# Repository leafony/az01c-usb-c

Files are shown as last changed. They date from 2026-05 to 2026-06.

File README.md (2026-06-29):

# Leafony AZ01C USB-C シリアル変換リーフ

## 概要

Leafony AZ01C は、Leafony Bus 向けの USB-C to UART リーフである。USB 接続時は FT234XD による USB-UART 変換と、USB VBUS から生成した 3.3V 電源を Leafony Bus へ供給する。

USB 未接続時に他リーフ側のバッテリーから 3.3V が供給される構成でも、UART 信号線と 3.3V 電源ラインのバックフィードを抑え、USB-C リーフ側が無駄な電力を消費しないことを設計方針とする。信号線は TS3A4741 で物理的に切断し、電源ラインは TPS6282533 出力と Leafony Bus 3.3V の間に MAX40200AUK+T 理想ダイオードを入れて逆流を遮断する。

## 主な用途

- Leafony リーフへの MCU 書き込み
- Leafony リーフの UART デバッグ
- USB から Leafony Bus への 3.3V 電源供給

## 仕様

### 電気的仕様

| 項目 | Min | Typ | Max | 単位 | 備考 |
|---|---:|---:|---:|---|---|
| USB VBUS 入力電圧 | 4.5 | 5.0 | 5.5 | V | USB-C UFP/Sink として使用 |
| Buck 出力電圧 `P3V3_BUCK` | 3.27 | 3.30 | 3.33 | V | TPS6282533 固定 3.3V、精度 ±1% |
| Leafony Bus 3.3V 出力 | - | 3.26 | - | V | MAX40200 通過後。500mA 時は約 43mV 低下 |
| Leafony Bus 3.3V 出力電流 | - | - | 500 | mA | TPS6282533 は 2A 品、MAX40200 は 1A 品。本設計では 500mA 上限 |
| MAX40200 逆方向リーク | - | 0.07 | 1.5 | µA | Leafony Bus +3.3V から `P3V3_BUCK` 方向 |
| UART 通信速度 | 300 | - | 3,000,000 | baud | FT234XD 仕様 |
| UART I/O 論理電圧 | - | 3.3 | - | V | FT234XD VCCIO を Leafony Bus 3.3V rail に接続 |
| USB 接続時アイドル消費 | - | 12 | - | mA | FT234XD、Buck、MAX40200、LED 周辺を含む概算 |
| USB 未接続時バッテリー側消費 | - | 0.15 | 2.3 | µA | MAX40200 逆方向リークと TS3A4741 待機電流のデータシート値から算出。FT234XD の VCC=0V、VCCIO=3.3V 条件は実機確認対象 |
| 動作温度範囲 | -40 | 25 | +85 | ℃ | 構成部品の最小共通範囲 |

### 機械的仕様

| 項目 | 仕様 |
|---|---|
| 外形寸法 | Leafony 20mm x 20mm |
| 基板厚 | 0.8mm 推奨 |
| 層数 | 4層 |
| 実装 | 両面実装 |
| USB コネクタ | Hirose CX90M-16P |
| 外部接続 | Leafony Bus 29ピン |

### USB 仕様

| 項目 | 仕様 |
|---|---|
| USB 規格 | USB 2.0 Full Speed (12Mbps) |
| コネクタ | USB Type-C |
| Type-C ロール | UFP / Sink Only |
| CC 抵抗 | CC1, CC2 それぞれ 5.1kΩ で GND へプルダウン |
| USB PD | 非対応 |
| ドライバ | FTDI VCP / D2XX |

## 回路設計

### 電源アーキテクチャ

```
USB VBUS 5V
  |
  +-- FB1 ---------------------> FT234XD.VCC
  |                                |
  |                                +--> FT234XD.3V3OUT
  |                                      |
  |                                      +--> TS3A4741.IN1/IN2
  |
  +----------------------------> TPS6282533.VIN
                                   |
                                   +-- EN = VIN
                                   |
                                   +-- SW -- L1 --> P3V3_BUCK
                                                   |
                                                   +--> MAX40200AUK+T
                                                        VDD = P3V3_BUCK
                                                        EN  = VDD
                                                        OUT = +3.3V rail
                                                              |
                                                              +--> FT234XD.VCCIO
                                                              +--> TS3A4741.V+
                                                              +--> LED1 pull-up
                                                              +--> Leafony Bus 3.3V (CN1 F1/B1)
```

`P3V3_BUCK` は TPS6282533 と MAX40200 の間のローカル電源レール、`+3.3V rail` は MAX40200 後段の Leafony Bus 側電源レールとする。

MAX40200 を入れることで、USB 未接続時に他リーフから Leafony Bus 3.3V が供給されても、`+3.3V rail -> P3V3_BUCK -> TPS6282533.SW/VIN -> VBUS` 方向の逆流を遮断する。MAX40200 の電圧降下により、Leafony Bus 側の実効電圧は TPS6282533 出力より低くなる。

### 動作状態

| 状態 | 電源 | UART 信号線 | 備考 |
|---|---|---|---|
| USB 接続、外部 3.3V なし | TPS6282533 から Leafony Bus へ 3.3V 供給 | TS3A4741 ON | 通常の USB-UART 動作 |
| USB 未接続、外部 3.3V なし | VBUS=0V、`P3V3_BUCK`=0V、Leafony Bus 3.3V=0V | TS3A4741 OFF | 基板側は実質停止 |
| USB 未接続、他リーフから 3.3V 供給 | Leafony Bus 3.3V は外部から印加。MAX40200 が Buck/VBUS 方向の逆流を遮断 | TS3A4741 OFF | FT234XD.3V3OUT=0V のためスイッチ制御は OFF |
| USB 接続、他リーフも 3.3V 供給 | 電源競合に注意 | TS3A4741 ON | 複数電源の同時接続を許容する場合はシステム側で電源 ORing 方針を確認 |

USB 未接続で他リーフから 3.3V が供給される場合、MAX40200 後段の `+3.3V rail` 配下である FT234XD.VCCIO、TS3A4741.V+、LED1 pull-up には電圧がかかる。一方で FT234XD.VCC は VBUS 由来のため 0V であり、FT234XD.3V3OUT も 0V となる。UART の TX/RX は TS3A4741 により切断される。

この状態でバッテリー側から USB-C リーフへ流れる消費電流は、データシート規定値からの見積もりで Typ 約 0.15µA、Max 約 2.3µA とする。内訳は MAX40200 の逆方向リーク Typ 0.07µA / Max 1.5µA と、TS3A4741 の VCC 待機電流 Typ 0.075µA / Max 0.75µA である。FT234XD は VCC=0V、VCCIO=3.3V の条件がデータシート上の通常動作条件ではないため、この見積もりには含めず、実機で USB 未接続時の Leafony Bus 3.3V 電流を確認する。

### バックフィード対策

バックフィード経路は大きく 2 つに分ける。

| 経路 | リスク | 対策 |
|---|---|---|
| UART TX/RX 信号線 | 他リーフ MCU の TX/RX が FT234XD の I/O 保護素子を通じて FT234XD 側を半端に給電する | TS3A4741 を TX/RX に直列挿入し、USB 未接続時は OFF |
| 3.3V 電源ライン | 他リーフの 3.3V が TPS6282533 の SW/L1 側から VIN/VBUS へ逆流する | MAX40200AUK+T を `P3V3_BUCK` と Leafony Bus 3.3V の間に直列挿入 |

TS3A4741 の IN1/IN2 は FT234XD.3V3OUT に接続する。USB 接続時は FT234XD が動作して 3V3OUT が High になり、TX/RX が接続される。USB 未接続時は 3V3OUT が 0V になり、TX/RX が物理的に切断される。

MAX40200 は VDD を `P3V3_BUCK`、OUT を Leafony Bus 3.3V、EN を VDD に接続する。USB 接続時は TPS6282533 から Leafony Bus へ給電し、USB 未接続時は Leafony Bus 3.3V から Buck/VBUS 側への逆流を遮断する。

### USB Type-C UFP 構成

| 信号 | 処理 |
|---|---|
| CC1, CC2 | 各々 5.1kΩ で GND へプルダウン |
| VBUS | A4, A9, B4, B9 をまとめて 5V 入力へ接続 |
| GND | A1, A12, B1, B12 を GND プレーンへ接続 |
| D+, D- | A面/B面の同名信号を基板上で接続し、FT234XD へ配線 |
| SBU1, SBU2 | NC |

USB PD には対応しない。CC 抵抗のみで USB Type-C の Sink/UFP として認識させる。

### ESD 保護

D+/D- ラインには USBLC6-2P6 を配置する。USB-C コネクタ近傍に置き、D+/D- へのスタブを短くする。VBUS は FB1 を通して基板内へ引き込む。必要に応じて、VBUS 用 TVS ダイオードの追加余地を検討する。

### 通信インジケータ LED

FT234XD の CBUS0 を FT_PROG で `TX&RXLED#` に設定し、LED1 を TX/RX 共用インジケータとして使用する。

## Leafony Bus ピンアサイン

| ピン名 | F面 / B面 | 信号 | 用途 |
|---|---|---|---|
| 3.3V | F1 / B1 | +3.3V rail | MAX40200 通過後の 3.3V 電源。USB から他リーフへ最大 500mA 供給 |
| VBUS | F3 / B3 | VBUS 5V | USB VBUS。必要な他リーフで参照可能 |
| D0 | F18 / B18 | UART TX | FT234XD TXD から他リーフ MCU RX へ。TS3A4741 Ch1 経由 |
| D1 | F20 / B20 | UART RX | 他リーフ MCU TX から FT234XD RXD へ。TS3A4741 Ch2 経由 |
| GND | F27 / B27 | GND | 共通グラウンド |

## 主要部品

| Ref | 型番 | 役割 |
|---|---|---|
| U1 | TS3A4741DCNR | UART TX/RX 切断用 2ch SPST アナログスイッチ |
| U2 | USBLC6-2P6 | USB D+/D- ESD 保護 |
| U3 | FT234XD | USB-UART ブリッジ |
| U4 | TPS6282533DMQR | 5V から 3.3V を生成する Buck コンバータ |
| U5 | MAX40200AUK+T | 3.3V 電源ライン逆流防止用 ideal diode |
| J1 | CX90M-16P | USB Type-C レセプタクル |
| L1 | 0.47uH | TPS6282533 用インダクタ |
| FB1 | 600Ω @ 100MHz | VBUS 入力ノイズ抑制 |

## ソフトウェア

### ドライバ

FTDI 公式の VCP または D2XX ドライバを使用する。

| OS | ドライバ | 備考 |
|---|---|---|
| Windows 10/11 | 標準ドライバ自動インストール | 必要に応じて FTDI 公式ドライバを使用 |
| macOS | 標準 Apple FTDI ドライバ | macOS 10.9 以降 |
| Linux | `ftdi_sio` | 多くのディストリビューションで自動認識 |

### 初期設定 (FT_PROG)

量産前に FT234XD 内蔵 MTP へ以下を設定する。

| パラメータ | 設定値 | 備考 |
|---|---|---|
| CBUS0 Function | `TX&RXLED#` | LED1 通信インジケータ用 |
| Manufacturer Name | 任意 | 例: `mitdir` |
| Product Description | 任意 | 例: `Leafony USB-UART Bridge` |
| Serial Number | ユニーク値 | 複数台接続時の識別用 |
| USB Vendor ID | `0x0403` | FTDI デフォルト |
| USB Product ID | `0x6015` | FT-X デフォルト |

## 設計反映メモ

この README は、MAX40200AUK+T を追加した電源構成を前提とする。KiCad 回路図、PCB、BOM を更新する場合は、少なくとも以下を反映する。

- `U5: MAX40200AUK+T` を追加する
- TPS6282533 の出力側を `P3V3_BUCK` とし、Leafony Bus 側 `+3.3V rail` と分離する
- MAX40200 の VDD を `P3V3_BUCK`、OUT を `+3.3V rail`、EN を VDD に接続する
- Leafony Bus 3.3V、FT234XD.VCCIO、TS3A4741.V+、LED1 pull-up は MAX40200 後段の `+3.3V rail` に接続する
- BOM に MAX40200AUK+T と対応フットプリントを追加する

あわせて以下を実機またはデータシートで確認する。

- USB 未接続かつ他リーフから 3.3V が供給される状態で、FT234XD.VCC=0V、FT234XD.VCCIO=3.3V となることを許容できるか
- USB 接続中に他リーフ側の 3.3V 電源も同時に有効になるシステム構成を許容するか
- MAX40200 の電圧降下込みで、Leafony Bus 側 3.3V rail の最小電圧が接続先リーフの要求を満たすか

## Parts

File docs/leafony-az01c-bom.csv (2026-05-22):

Reference | Value | Datasheet | Footprint | Qty | DNP | MANUFACTURER | MPN
C1,C2,C4,C5,C10 | 0.1uF(K)/50V/X5R | https://yageogroup.com/content/datasheet/asset/file/UPY-GPHC_X5R_4V-TO-50V | Capacitor_SMD:C_0402_1005Metric | 5 |  | YAGEO | CC0402KRX5R9BB104
C3 | 4.7uF(M)/6.3V/X5R | https://yageogroup.com/content/datasheet/asset/file/UPY-GPHC_X5R_4V-TO-50V | Capacitor_SMD:C_0402_1005Metric | 1 |  | YAGEO | CC0402MRX5R5BB475
C6 | 10nF(K)/50V/X7R | https://yageogroup.com/content/datasheet/asset/file/UPY-GPHC_X7R_6.3V-TO-50V | Capacitor_SMD:C_0402_1005Metric | 1 |  | YAGEO | CC0402KRX7R9BB103
C7 | 4.7uF(K) 10V X5R | https://yageogroup.com/content/datasheet/asset/file/UPY-GPHC_X5R_4V-TO-50V | Capacitor_SMD:C_0603_1608Metric | 1 |  | YAGEO | CC0603KRX5R6BB475
C8,C9 | 10uF(M) 10V X5R | https://yageogroup.com/content/datasheet/asset/file/UPY-GPHC_X5R_4V-TO-50V | Capacitor_SMD:C_0603_1608Metric | 2 |  | YAGEO | CC0603MRX5R6BB106
D1 | Red LED | https://www.rohm.com/products/led/chip-leds-mono-color-type/standard/sml-d14vw_a_-product | LED_SMD:LED_0603_1608Metric | 1 |  | ROHM | SML-D14VWT86AAS
FB1 | 600 Ohms @ 100 MHz | https://www.laird.com/document/datasheet/mi0805k601r-10-datasheet | Inductor_SMD:L_0805_2012Metric | 1 |  | Laird | MI0805K601R-10
J1 | CX90M-16P | https://www.hirose.com/product/document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 | Leafony:HRS_CX90M-16P | 1 |  | Hirose | CX90M-16P
L1 | 0.47uH(M) 3.6A | https://search.murata.co.jp/Ceramy/image/img/P02/J(E)TE243A-0001.pdf | Inductor_SMD:L_Murata_DFE201610P | 1 |  | Murata Electronics | DFE201610E-R47M=P2
R1 | 10k(J) | https://yageogroup.com/content/datasheet/asset/file/PYU-RC_GROUP_51_ROHS_L | Resistor_SMD:R_0402_1005Metric | 1 |  | YAGEO | RC0402JR-0710KL
R2 | 270R(J) | https://yageogroup.com/content/datasheet/asset/file/PYU-RC_GROUP_51_ROHS_L | Resistor_SMD:R_0402_1005Metric | 1 |  | YAGEO | RC0402JR-07270RL
R3,R4 | 5.1k(J) | https://yageogroup.com/content/datasheet/asset/file/PYU-RC_GROUP_51_ROHS_L | Resistor_SMD:R_0402_1005Metric | 2 |  | YAGEO | RC0402JR-075K1L
U1 | TS3A4741DCNR | https://www.ti.com/lit/gpn/ts3a4741 | Package_TO_SOT_SMD:SOT-23-8 | 1 |  | Texas Instruments | TS3A4741DCNR
U2 | USBLC6-2P6 | https://www.st.com/resource/en/datasheet/usblc6-2.pdf | Package_TO_SOT_SMD:SOT-666 | 1 |  | STMicroelectronics | USBLC6-2P6
U3 | FT234XD | https://ftdichip.com/wp-content/uploads/2024/05/DS_FT234XD.pdf | Package_DFN_QFN:WDFN-12-1EP_3x3mm_P0.45mm_EP1.7x2.5mm | 1 |  | FTDI | FT234XD-T
U4 | TPS6282533DMQR | https://www.ti.com/lit/gpn/tps62825 | Leafony:DMQ0006A | 1 |  | Texas Instruments | TPS6282533DMQR
U5 | MAX40200AUK+T | https://datasheets.maximintegrated.com/en/ds/MAX40200.pdf | Package_TO_SOT_SMD:SOT-23-5 | 1 |  | Analog Devices Inc./Maxim Integrated | MAX40200AUK+T

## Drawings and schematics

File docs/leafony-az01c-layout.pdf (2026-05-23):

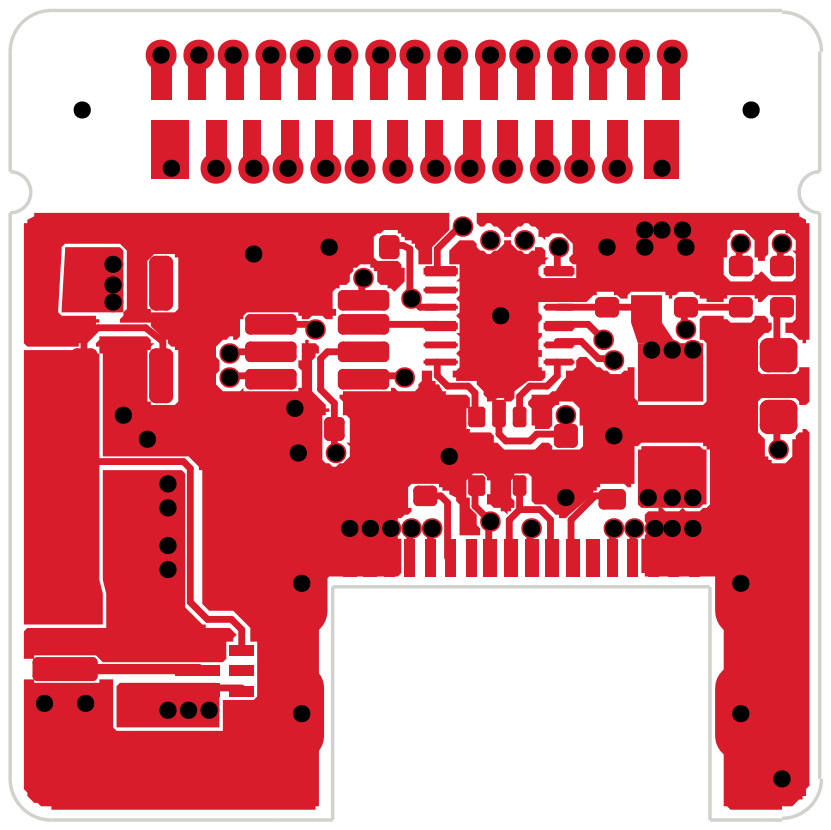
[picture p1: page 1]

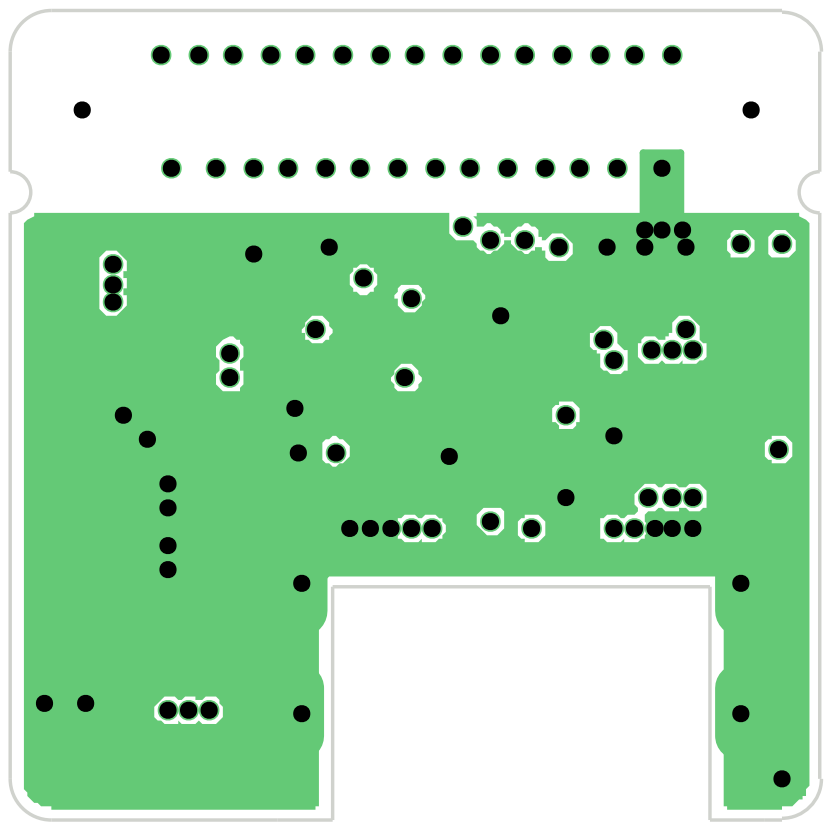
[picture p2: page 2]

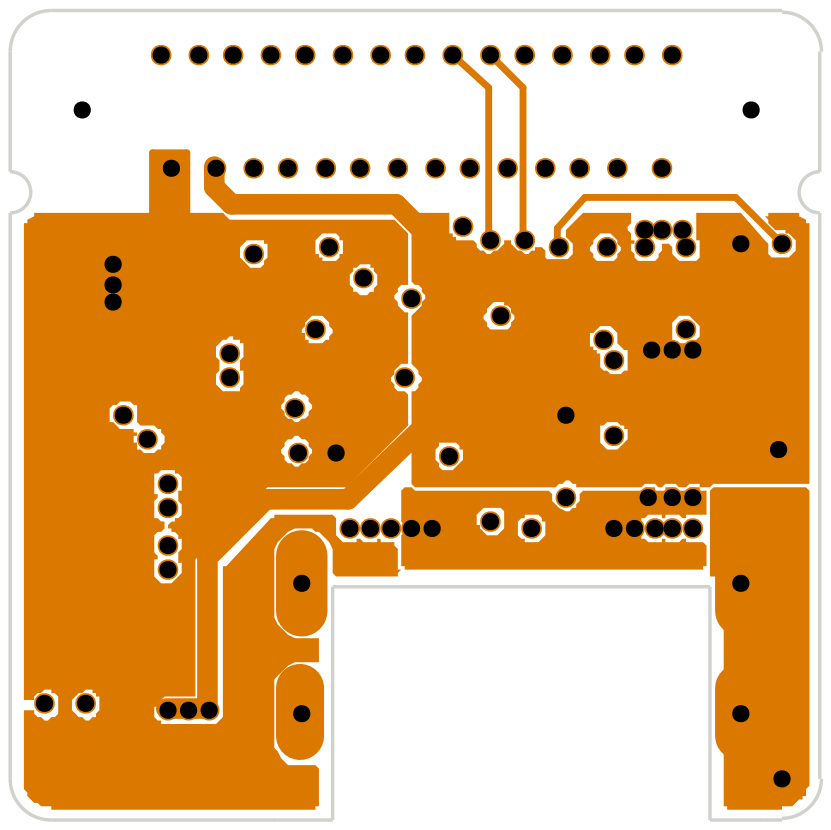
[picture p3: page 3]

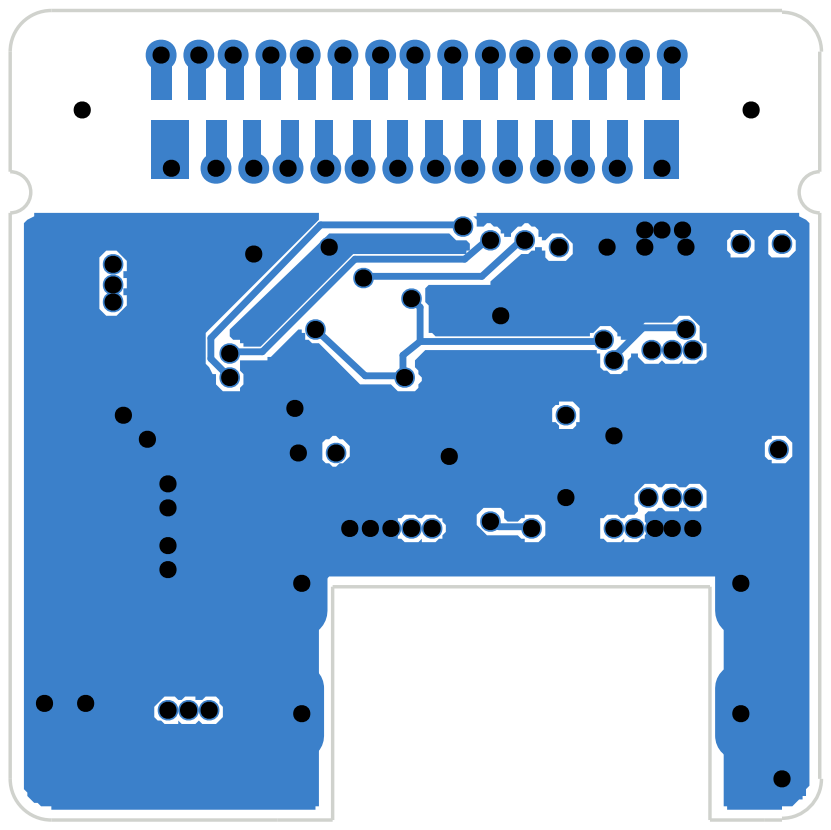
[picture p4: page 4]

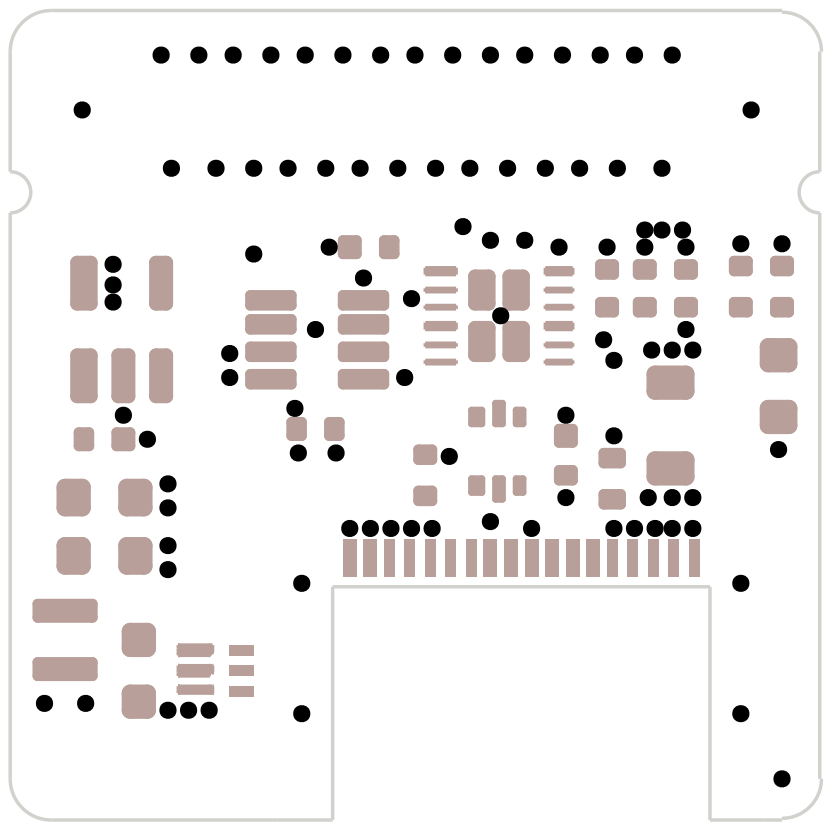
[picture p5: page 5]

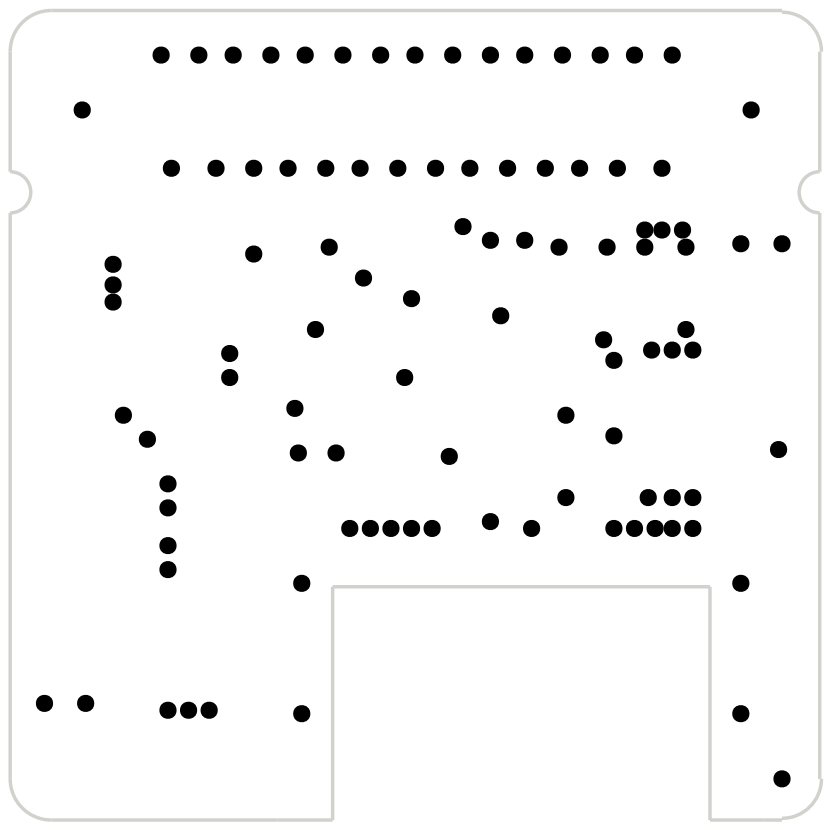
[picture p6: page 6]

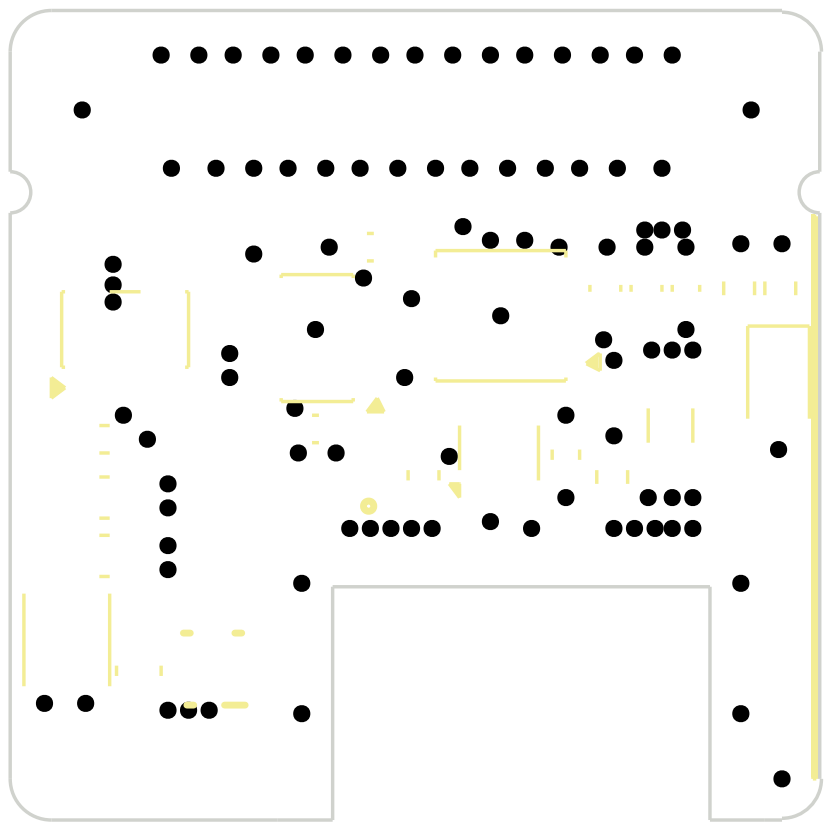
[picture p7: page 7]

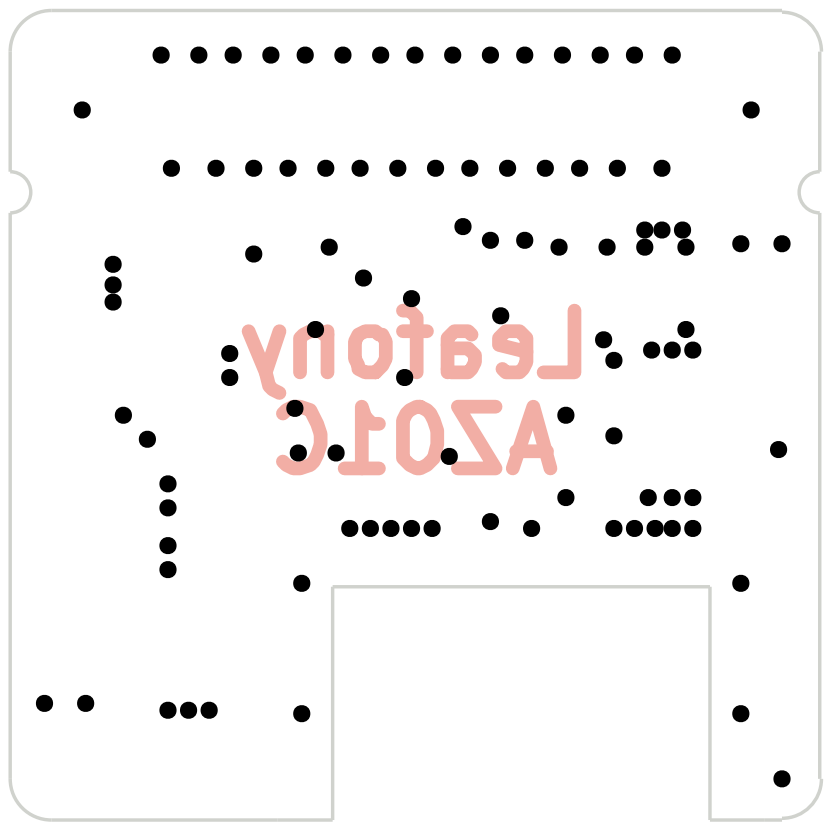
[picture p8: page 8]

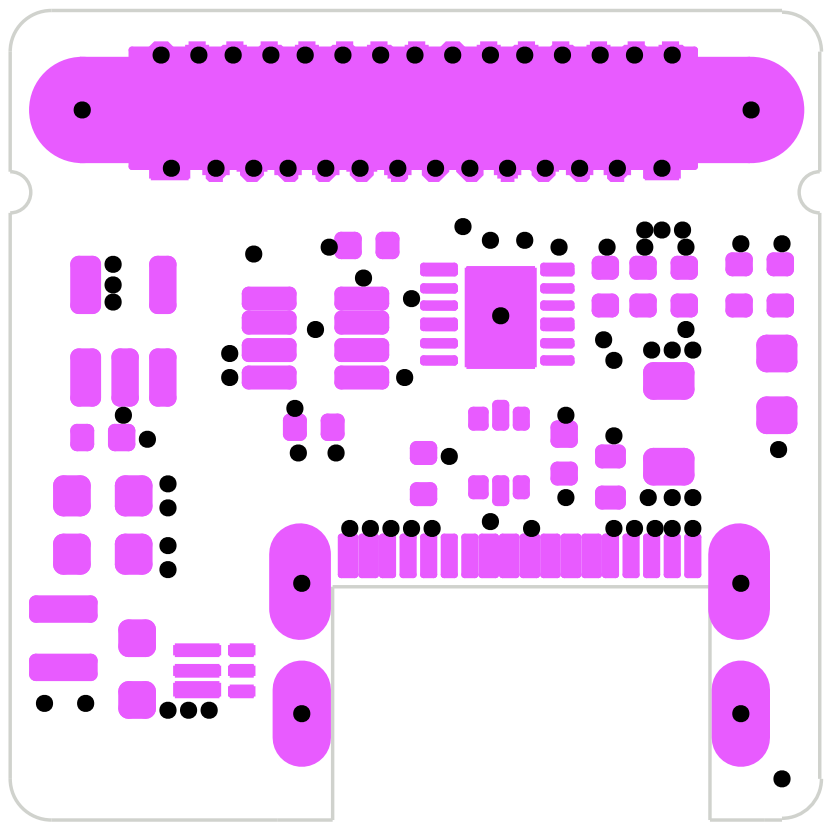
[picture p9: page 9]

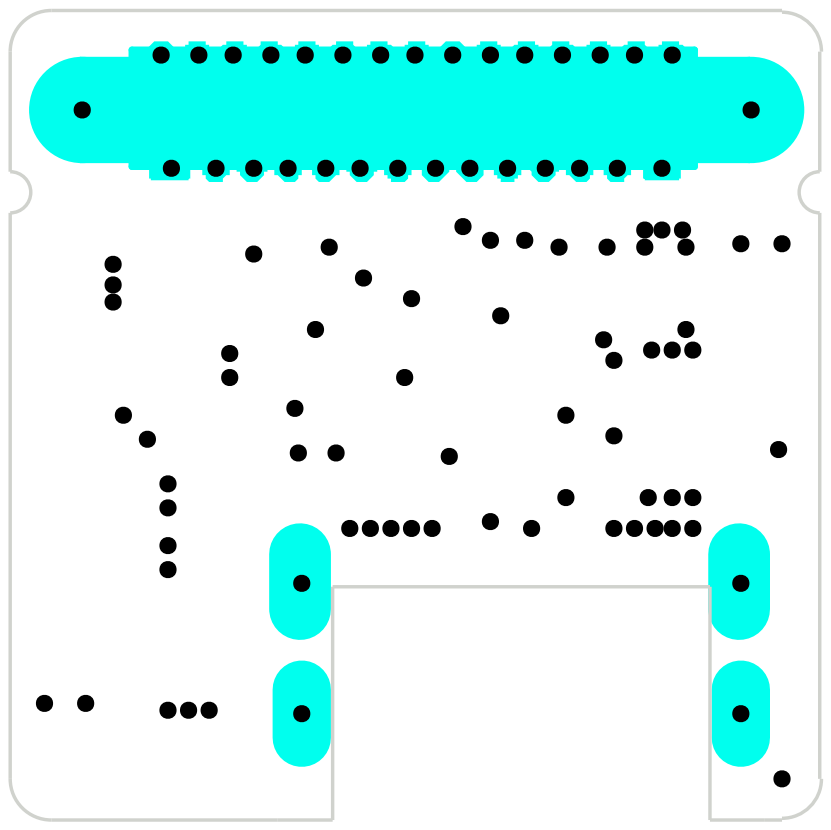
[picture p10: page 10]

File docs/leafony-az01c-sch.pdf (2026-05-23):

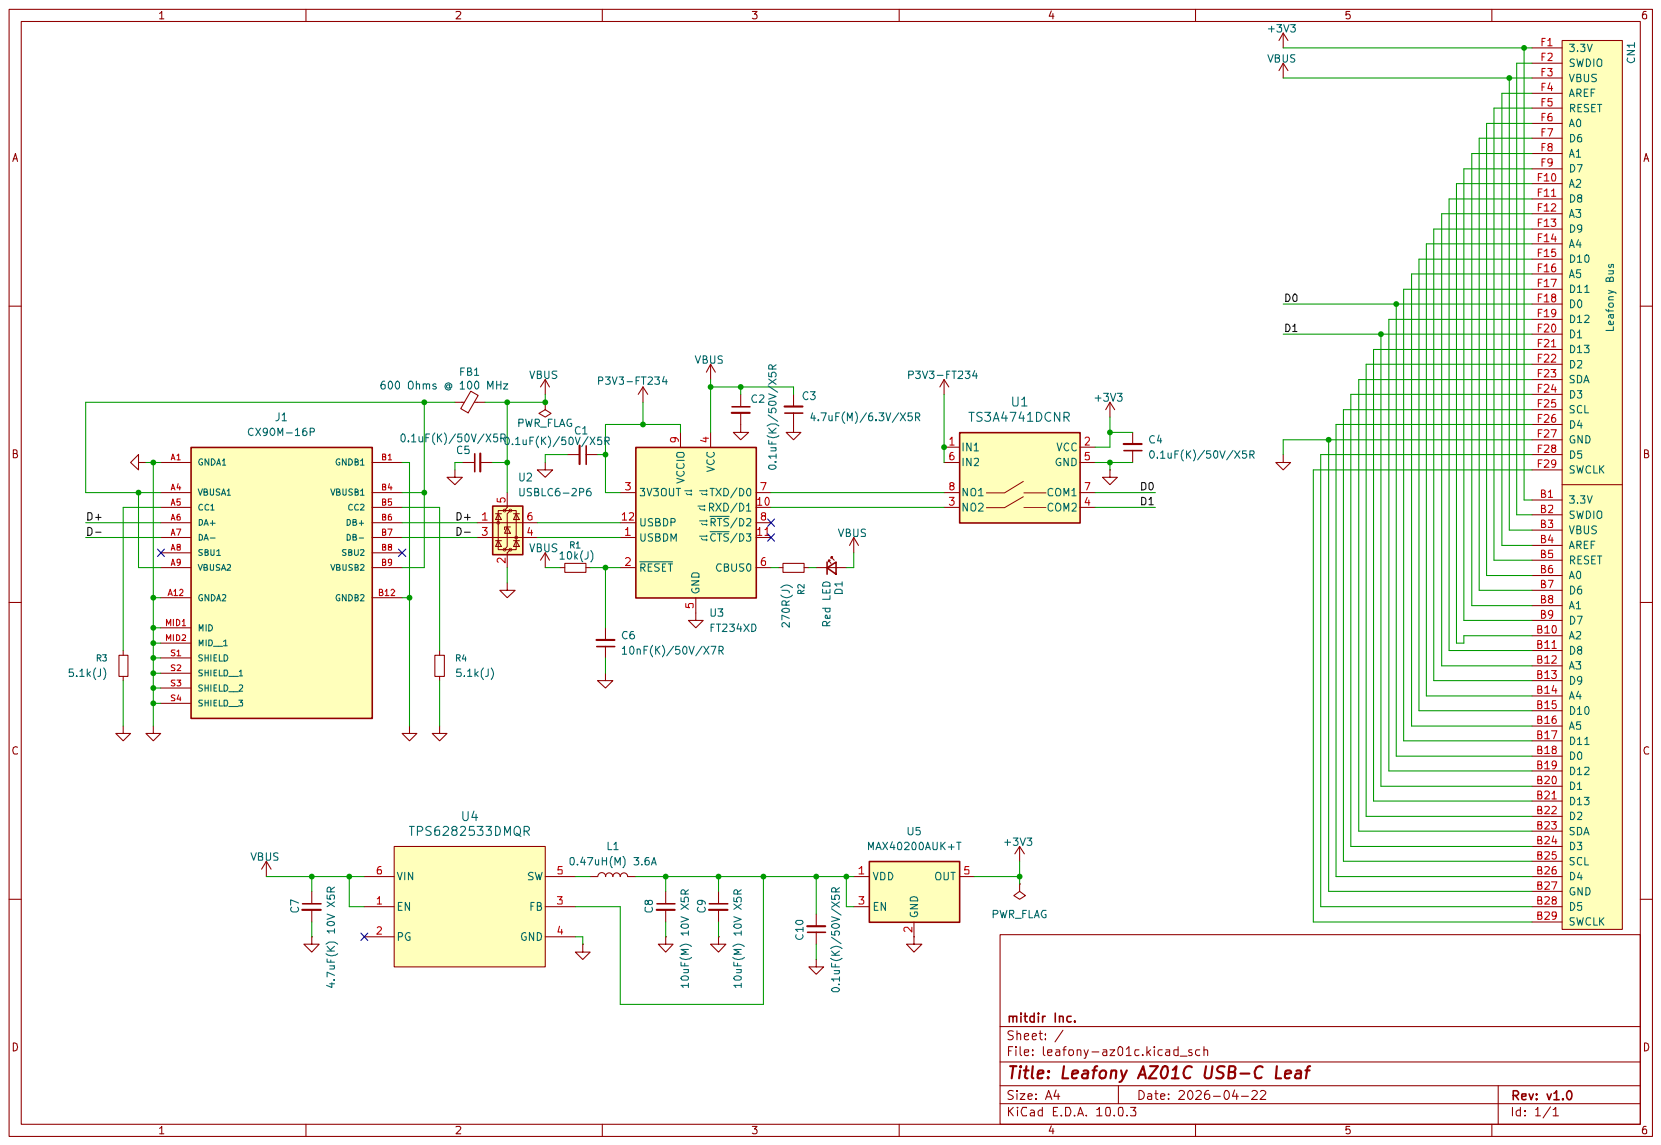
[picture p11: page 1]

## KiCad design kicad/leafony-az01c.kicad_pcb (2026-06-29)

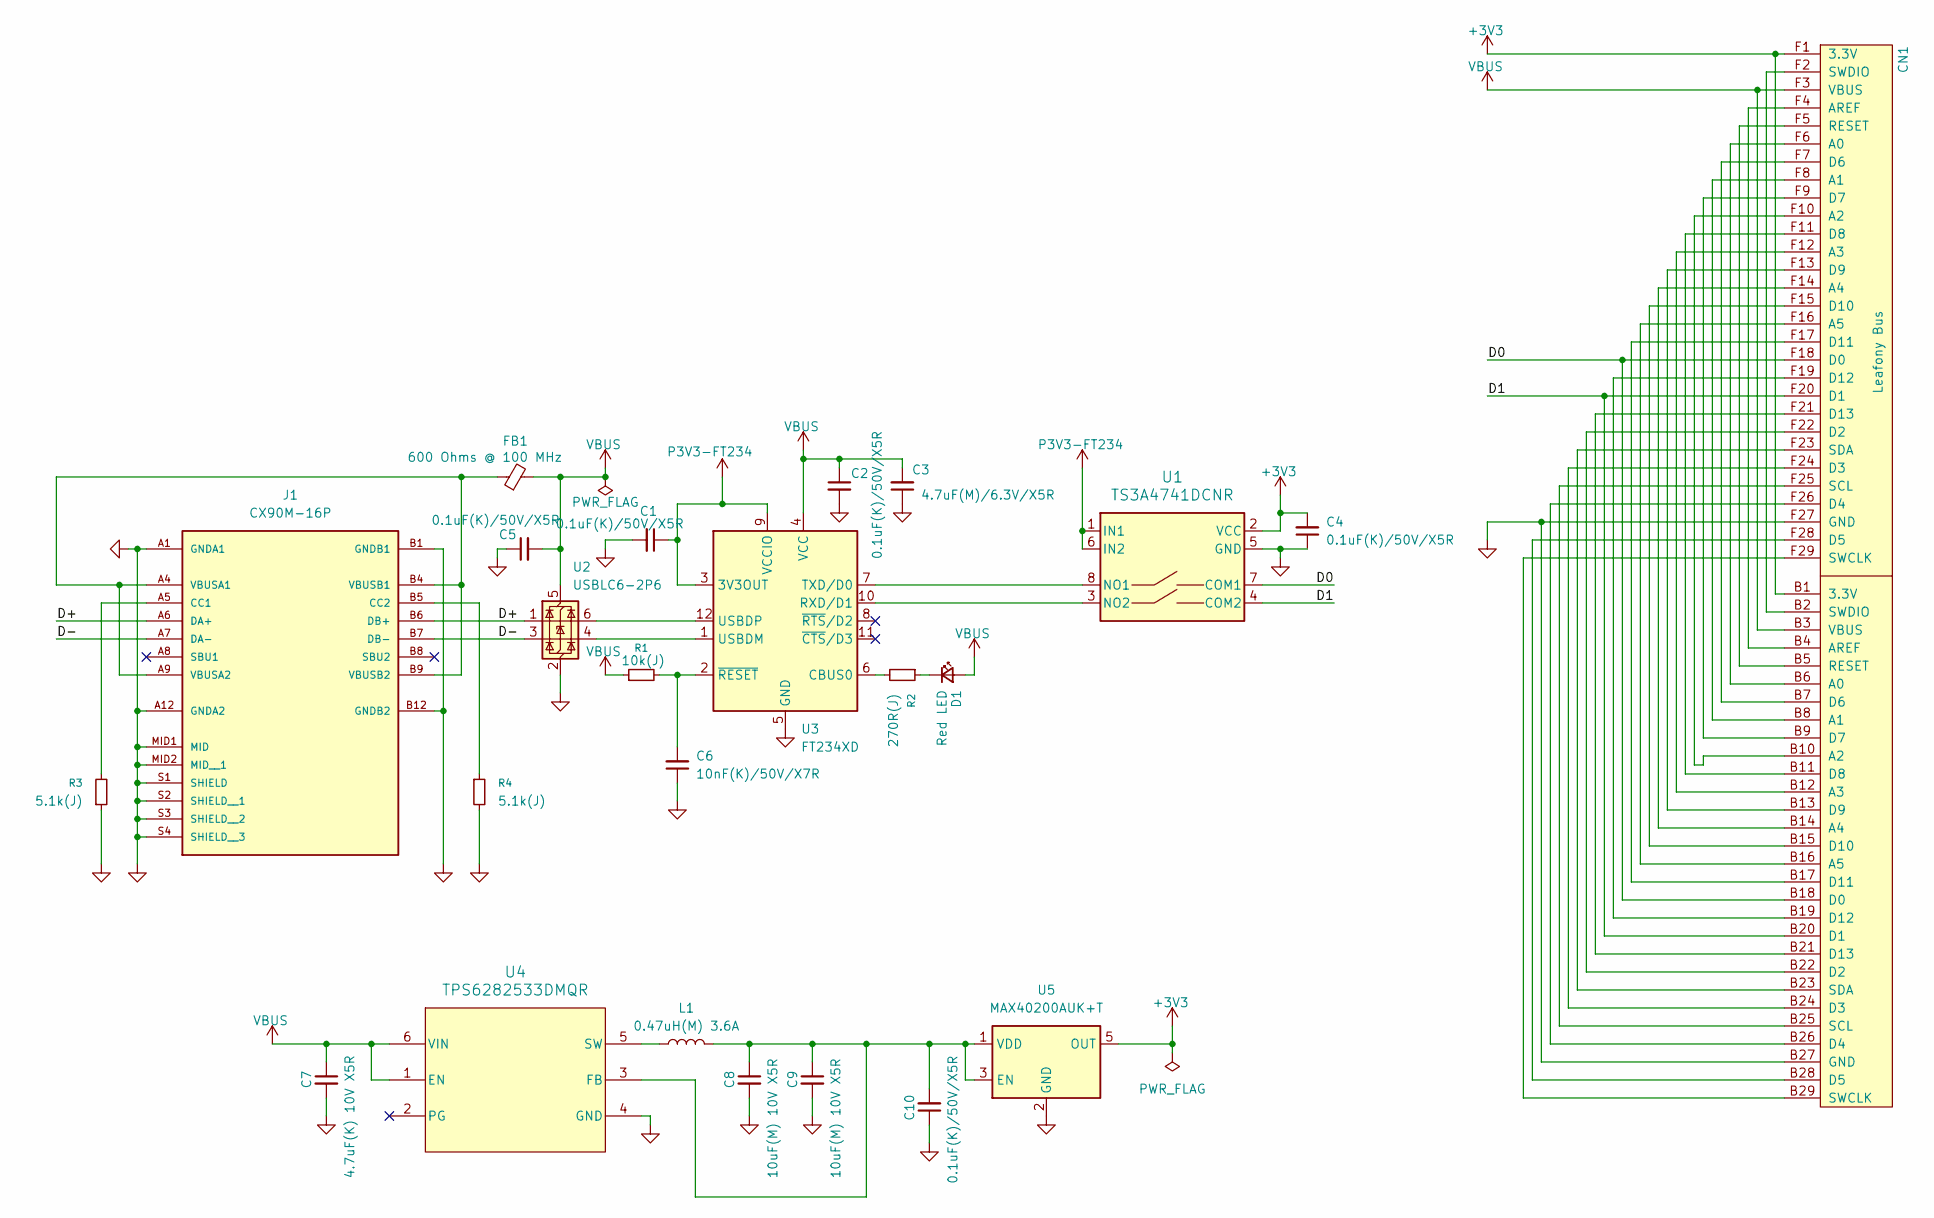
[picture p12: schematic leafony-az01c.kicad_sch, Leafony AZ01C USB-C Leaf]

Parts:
C1, C2, C4, C5, C10: 0.1uF(K)/50V/X5R; C_0402_1005Metric; MPN CC0402KRX5R9BB104
C3: 4.7uF(M)/6.3V/X5R; C_0402_1005Metric; MPN CC0402MRX5R5BB475
C6: 10nF(K)/50V/X7R; C_0402_1005Metric; MPN CC0402KRX7R9BB103
C7: 4.7uF(K) 10V X5R; C_0603_1608Metric; MPN CC0603KRX5R6BB475
C8, C9: 10uF(M) 10V X5R; C_0603_1608Metric; MPN CC0603MRX5R6BB106
CN1: Leafony Bus; CN_F29_B29
D1: Red LED; LED_0603_1608Metric; MPN SML-D14VWT86AAS
FB1: 600 Ohms @ 100 MHz; L_0805_2012Metric; MPN MI0805K601R-10
J1: CX90M-16P; HRS_CX90M-16P; PARTREV 2
L1: 0.47uH(M) 3.6A; L_Murata_DFE201610P; MPN DFE201610E-R47M=P2
R1: 10k(J); R_0402_1005Metric; MPN RC0402JR-0710KL
R2: 270R(J); R_0402_1005Metric; MPN RC0402JR-07270RL
R3, R4: 5.1k(J); R_0402_1005Metric; MPN RC0402JR-075K1L
U1: TS3A4741DCNR; SOT-23-8; MPN TS3A4741DCNR
U2: USBLC6-2P6; SOT-666; MPN USBLC6-2P6
U3: FT234XD; WDFN-12-1EP_3x3mm_P0.45mm_EP1.7x2.5mm; MPN FT234XD-T
U4: TPS6282533DMQR; DMQ0006A; MPN TPS6282533DMQR
U5: MAX40200AUK+T; SOT-23-5; MPN MAX40200AUK+T

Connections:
+3V3: C4.2, CN1.B1 (3.3V), CN1.F1 (3.3V), U1.2 (VCC), U5.5 (OUT)
/D0: CN1.B18 (D0), CN1.F18 (D0), U1.7 (COM1)
/D1: CN1.B20 (D1), CN1.F20 (D1), U1.4 (COM2)
/D+: J1.A6 (DA+), J1.B6 (DB+), U2.1 (I/O1)
/D-: J1.A7 (DA-), J1.B7 (DB-), U2.3 (I/O2)
GND: C1.2, C2.2, C3.1, C4.1, C5.1, C6.1, C7.2, C8.2, C9.2, C10.1, CN1.B27 (GND), CN1.F27 (GND), J1.A1 (GNDA1), J1.A12 (GNDA2), J1.B1 (GNDB1), J1.B12 (GNDB2), J1.MID1 (MID), J1.MID2 (MID__1), J1.S1 (SHIELD), J1.S2 (SHIELD__1), J1.S3 (SHIELD__2), J1.S4 (SHIELD__3), R3.1, R4.2, U1.5 (GND), U2.2 (GND), U3.5 (GND), U3.13 (GND), U4.4 (GND), U5.2 (GND)
unnamed: CN1.B6 (A0), CN1.F6 (A0)
unnamed: CN1.B8 (A1), CN1.F8 (A1)
unnamed: CN1.B10 (A2), CN1.F10 (A2)
unnamed: CN1.B12 (A3), CN1.F12 (A3)
unnamed: CN1.B14 (A4), CN1.F14 (A4)
unnamed: CN1.B16 (A5), CN1.F16 (A5)
unnamed: CN1.B4 (AREF), CN1.F4 (AREF)
unnamed: CN1.B22 (D2), CN1.F22 (D2)
unnamed: CN1.B24 (D3), CN1.F24 (D3)
unnamed: CN1.B26 (D4), CN1.F26 (D4)
unnamed: CN1.B28 (D5), CN1.F28 (D5)
unnamed: CN1.B7 (D6), CN1.F7 (D6)
unnamed: CN1.B9 (D7), CN1.F9 (D7)
unnamed: CN1.B11 (D8), CN1.F11 (D8)
unnamed: CN1.B13 (D9), CN1.F13 (D9)
unnamed: CN1.B15 (D10), CN1.F15 (D10)
unnamed: CN1.B17 (D11), CN1.F17 (D11)
unnamed: CN1.B19 (D12), CN1.F19 (D12)
unnamed: CN1.B21 (D13), CN1.F21 (D13)
unnamed: CN1.B5 (RESET), CN1.F5 (RESET)
unnamed: CN1.B25 (SCL), CN1.F25 (SCL)
unnamed: CN1.B23 (SDA), CN1.F23 (SDA)
unnamed: CN1.B29 (SWCLK), CN1.F29 (SWCLK)
unnamed: CN1.B2 (SWDIO), CN1.F2 (SWDIO)
unnamed: D1.1 (K), R2.1
unnamed: J1.A5 (CC1), R3.2
unnamed: J1.B5 (CC2), R4.1
unnamed: FB1.1, J1.A4 (VBUSA1), J1.A9 (VBUSA2), J1.B4 (VBUSB1), J1.B9 (VBUSB2)
unnamed: U1.8 (NO1), U3.7 (TXD/D0)
unnamed: U1.3 (NO2), U3.10 (RXD/D1)
unnamed: R2.2, U3.6 (CBUS0)
unnamed: U2.4 (I/O2), U3.1 (USBDM)
unnamed: U2.6 (I/O1), U3.12 (USBDP)
unnamed: C6.2, R1.2, U3.2 (~RESET)
unnamed: C8.1, C9.1, C10.2, L1.2, U4.3 (FB), U5.1 (VDD), U5.3 (EN)
unnamed: L1.1, U4.5 (SW)
P3V3-FT234: C1.1, U1.1 (IN1), U1.6 (IN2), U3.3 (3V3OUT), U3.9 (VCCIO)
VBUS: C2.1, C3.2, C5.2, C7.1, CN1.B3 (VBUS), CN1.F3 (VBUS), D1.2 (A), FB1.2, R1.1, U2.5 (VBUS), U3.4 (VCC), U4.1 (EN), U4.6 (VIN)

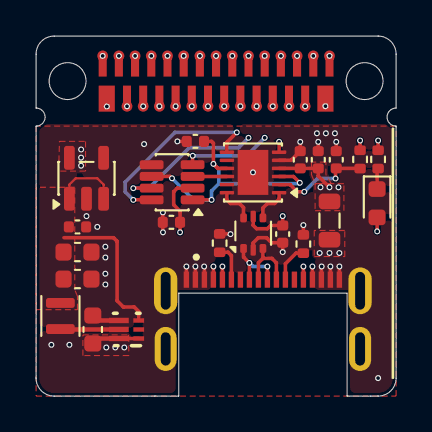
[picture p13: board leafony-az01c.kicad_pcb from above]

Board: 4 copper layers, 20.0 x 20.0 mm, 24 parts (0 on the bottom side), 44 nets.

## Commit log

2026-04-26 ディレクトリを整理
    [leafony-az01c.kicad_pcb, leafony-az01c.kicad_sch]
2026-04-26 BOMを出力
    [leafony-az01c-bom.csv]
2026-04-26 ガーバーを出力
    [leafony-az01c-panelized-B_Cu.gbl, leafony-az01c-panelized-B_Mask.gbs, leafony-az01c-panelized-B_Paste.gbp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]
2026-05-11 BOM修正
    [leafony-az01c-bom.csv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]
2026-05-22 面付基板を更新
2026-05-22 kicad 10
    [leafony-az01c.kicad_pcb, leafony-az01c.kicad_sch]
2026-05-22 MAX40200AUK+Tに関する記述を追加
    [leafony-az01c.kicad_pcb]
2026-05-22 README.mdの内容を更新し、MAX40200AUK+Tを追加した電源構成に関する詳細を反映
2026-05-22 BOMとガーバーを更新
    [leafony-az01c-bom.csv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]
2026-05-23 回路図とレイアウトを更新
2026-06-29 README.mdの内容を更新し、USB未接続時の消費電流に関する詳細を追加
    [leafony-az01c.kicad_pcb]
2026-11-14 Merge pull request #1 from leafony/ci/kicad-pdf-export
    回路図・レイアウトPDFをoutputへ自動生成
